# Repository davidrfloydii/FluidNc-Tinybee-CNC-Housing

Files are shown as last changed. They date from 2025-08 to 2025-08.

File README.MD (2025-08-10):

# Overview
This repository contains the CAD, config, and other files for a custom CNC housing. The goal was to make a destkop case that could hold all of the following:
-  Power Supply
-  Three DM556 Stepper Motor Drivers
-  The Tinybee board
-  Three aircraft connectors to go to the machine itself
-  A connector for the Z-Probe
-  Two buttons for pause and resume features
-  The GRBL_SPD board
-  A manual override switch for GRBL_SPD spindle speed
-  A potentiometer for the GRBL_SPD spindle speed
-  A power connection and switch

The case has a wrap around cover allowing for access to the components.

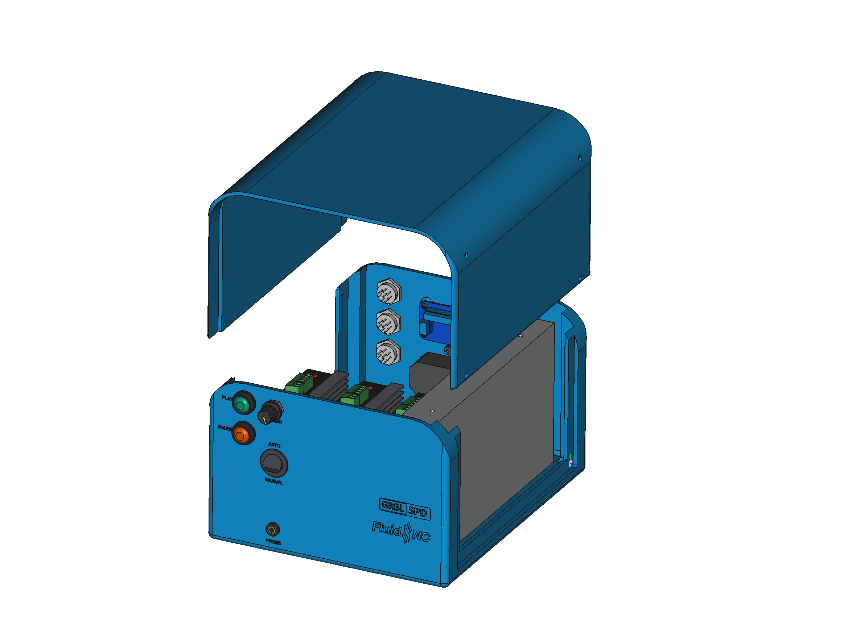
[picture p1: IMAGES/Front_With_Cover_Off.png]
Case Design


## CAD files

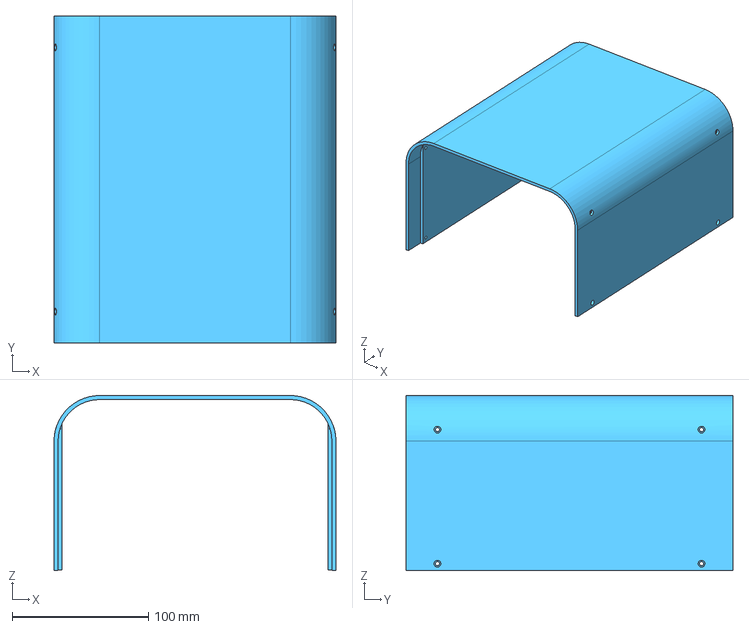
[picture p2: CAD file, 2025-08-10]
STEP/CustomCncCase-BodyCaseCover.step
207.2 x 240.0 x 128.6 mm

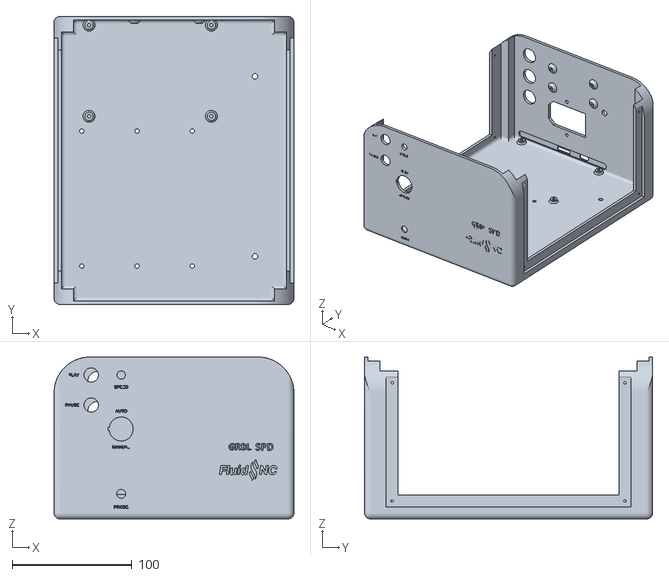
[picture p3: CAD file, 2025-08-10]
STL/BodyCaseBottom.stl
200.0 x 240.1 x 135.0

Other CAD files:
STEP/CustomCncCase-BodyCaseBottom.step
STL/BodyCaseCover.stl

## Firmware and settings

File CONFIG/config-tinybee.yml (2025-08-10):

board: MKS TinyBee V1.0 XYZ
name: Grbl 1.1g

kinematics:
  Cartesian:

i2so:
  bck_pin: gpio.25
  data_pin: gpio.27
  ws_pin: gpio.26

spi:
  miso_pin: gpio.19
  mosi_pin: gpio.23
  sck_pin: gpio.18

sdcard:
  cs_pin: gpio.5
  # uses TH2 IO34 active low - MAKE SURE jumper J2 is set to SDDET!!!
  card_detect_pin: gpio.34:low

stepping:
  engine: I2S_STATIC
  idle_ms: 255
  pulse_us: 4
  dir_delay_us: 1
  disable_delay_us: 2

axes:
  x:
    steps_per_mm: 800
    max_rate_mm_per_min: 4000.000
    acceleration_mm_per_sec2: 80.000
    max_travel_mm: 300
    soft_limits: false
    homing:
      cycle: 2
      positive_direction: false
      mpos_mm: 0.000
      feed_mm_per_min: 300.000
      seek_mm_per_min: 4000.000
      settle_ms: 500
      seek_scaler: 1.100
      feed_scaler: 1.100

    motor0:
      limit_neg_pin: gpio.33:low:pu
      hard_limits: true
      pulloff_mm: 4.000
      stepstick:
        step_pin: I2SO.1
        direction_pin: I2SO.2
        disable_pin: I2SO.0

  y:
    steps_per_mm: 800
    max_rate_mm_per_min: 4000.000
    acceleration_mm_per_sec2: 70.000
    max_travel_mm: 300
    soft_limits: false
    homing:
      cycle: 3
      positive_direction: false
      mpos_mm: 0.000
      feed_mm_per_min: 300.000
      seek_mm_per_min: 4000.000
      settle_ms: 500
      seek_scaler: 1.100
      feed_scaler: 1.100

    motor0:
      limit_neg_pin: gpio.32:low:pu
      hard_limits: false
      pulloff_mm: 4.000
      stepstick:
        step_pin: I2SO.4
        direction_pin: I2SO.5
        disable_pin: I2SO.3

  z:
    steps_per_mm: 800
    max_rate_mm_per_min: 4000.000
    acceleration_mm_per_sec2: 60.000
    max_travel_mm: 77.000
    soft_limits: false
    homing:
      cycle: 1
      positive_direction: true
      mpos_mm: 0.000
      feed_mm_per_min: 300.000
      seek_mm_per_min: 500.000
      settle_ms: 500
      seek_scaler: 1.100
      feed_scaler: 1.100

    motor0:
      limit_pos_pin: gpio.22:low:pu
      hard_limits: true
      pulloff_mm: 3.000
      stepstick:
        step_pin: I2SO.7
        direction_pin: I2SO.8
        disable_pin: I2SO.6

control:
  safety_door_pin: NO_PIN
  # on MT_DET connector
  reset_pin: NO_PIN
  # on TH1 connector
  feed_hold_pin: gpio.36:low
  # on TB connector
  cycle_start_pin: gpio.39:low
  macro0_pin: NO_PIN
  macro1_pin: NO_PIN
  macro2_pin: NO_PIN
  macro3_pin: NO_PIN

probe:
  pin: gpio.35:low
  check_mode_start: true

# coolant:
  # Heated Bed Terminal Block
  # flood_pin: i2so.16
  # HE0 Terminal Block
  # mist_pin: i2so.17
  # delay_ms: 0

# spindle PWM signal
PWM:
  pwm_hz: 1000
  direction_pin: NO_PIN
  output_pin: gpio.17
  disable_with_s0: false
  s0_with_disable: true
  spinup_ms: 0
  spindown_ms: 0
  tool_num: 0
  speed_map: 0=0.000% 10000=1.000% 30000=100.000% 

start:
  must_home: false

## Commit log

2025-08-10 Adding the CAD file for the case
2025-08-10 Adding config with GRBL_SPD control PWM
2025-08-10 Adding step versions and STL of the case
    [BodyCaseBottom.stl, BodyCaseCover.stl, CustomCncCase-BodyCaseBottom.step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]
